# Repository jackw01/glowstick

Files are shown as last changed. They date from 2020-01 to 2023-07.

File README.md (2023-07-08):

# Glowstick

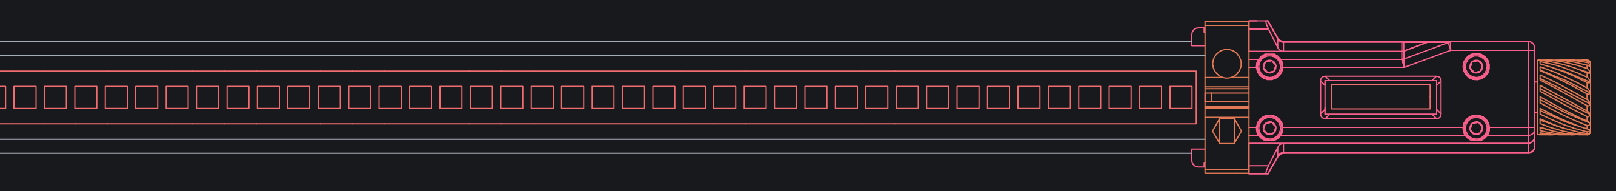
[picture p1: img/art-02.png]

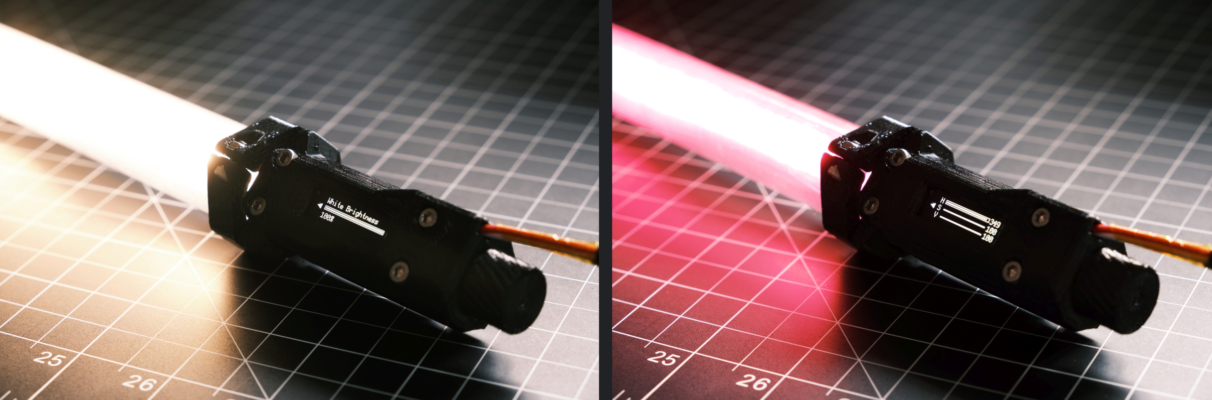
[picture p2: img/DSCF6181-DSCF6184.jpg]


## Features
* Full onboard control with OLED display and rotary encoder
* Uses a SK6812 LED strip for white and RGB light
* Color, white, and gradient modes for full control over lighting
* Animation modes for light painting
* Powered over USB or any other 5V source
* BOM cost less than US$50 for a 24" long light

## Hardware
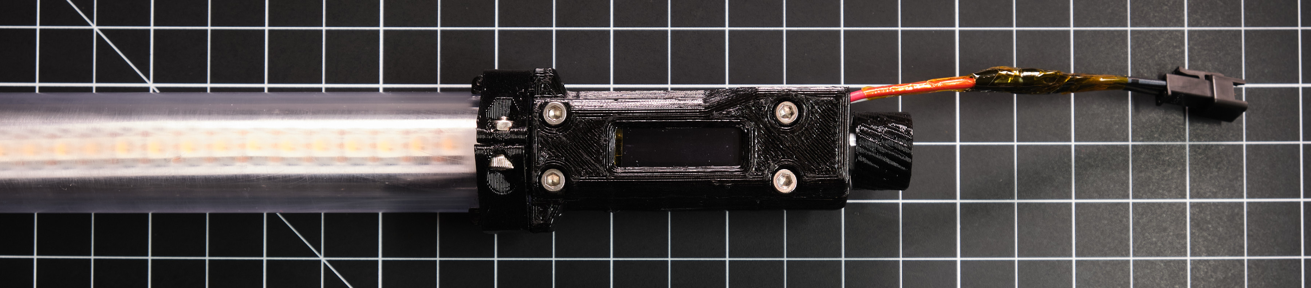
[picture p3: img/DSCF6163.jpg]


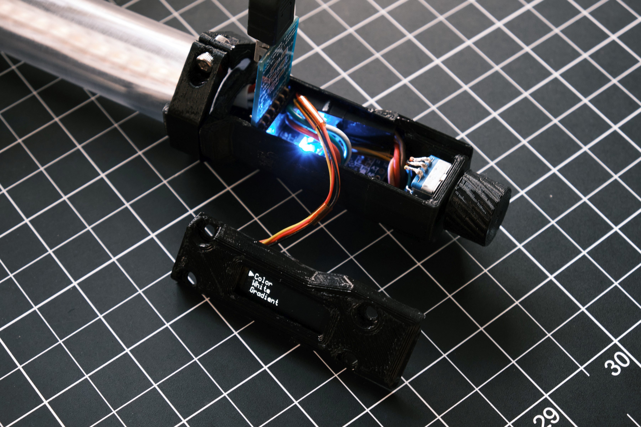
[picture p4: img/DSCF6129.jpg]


### Components used
* Arduino Pro Mini or Pololu A-Star 328PB Micro
* SK6812 RGBW LED strip, 1m length, 144 LED/m IP30
* SSD1306 I2C OLED display breakout board, 128x32 pixels
* EC11 series rotary encoder, push button switch, 15mm knurled shaft (EC11M)
* Clear polycarbonate tube, 1" OD 0.75" ID, 24" length
* Diffusion gel, 24"x1.5" (optional)
* M3 hex socket head cap screws, 4x 20mm and 2x 8mm; 6x M3 hex nuts

## Software

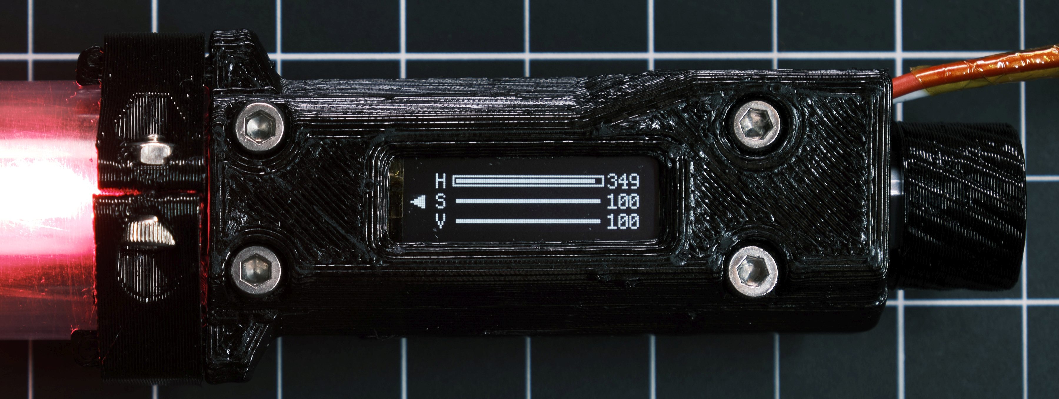
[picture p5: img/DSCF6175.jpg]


[U8g2](https://github.com/olikraus/u8g2) is used for controlling the display and [FastLED](https://github.com/FastLED/FastLED) is used for controlling the LED strips, with some hacks to make it work with RGBW LEDs.

The firmware is built using [PlatformIO](http://docs.platformio.org/en/latest/ide.html#platformio-ide).

## Build your own

### Wiring
All Arduino pin assignments are set in constants.hpp. The defaults are shown below:

```c++
const uint8_t PinLEDs = 2;
const uint8_t PinEncoderA = 3; // must be an external interupt pin
const uint8_t PinEncoderB = 4;
const uint8_t PinEncoderButton = 5;
```

The other contacts for the encoder and button are connected to ground. The display I2C pins connect to Arduino pins A4 (SDA) and A5 (SCL). The 5V and ground wires on the LED strip's connector are connected to the Arduino 5V and ground lines.

### 3D printed parts
STL files for all 3D printed parts can be found in the 3d-printing folder. The original Solidworks design files can be downloaded [here](https://1drv.ms/f/s!AsRZF_y9JrDUn5YvIyRrr59VbNJ60w?e=BrQjPf). All parts should be printed at 100% infill. Supports are required for 20-stick-p001 electronics enclosure, 20-stick-p003 electronics enclosure cover, and 20-stick-p005 encoder knob. I printed everything in PETG; any material should work but stronger ones are recommended. Disable x/y size compensation when printing 20-stick-p005 encoder knob.

There is intentionally no spot in the 3D printed housing for mounting a power connector, as the LED strips used may or may not come with a pre-attached barrel jack and some may prefer a completely different connector type instead. Even with 84 LEDs, current draw is low enough that everything can be powered by a standard USB power bank capable of supplying 2-2.4A at 5V.

The Arduino Pro Mini and the OLED Display are mounted using 3M VHB tape cut to fit the mounting surfaces on their respective parts. The electronics enclosure is designed to accomodate a Pro Mini with a vertical programming header. If yours has a right-angle header, it can be bent up and trimmed by about 2mm to match the dimensions of a vertical header.

### LED strip mounting
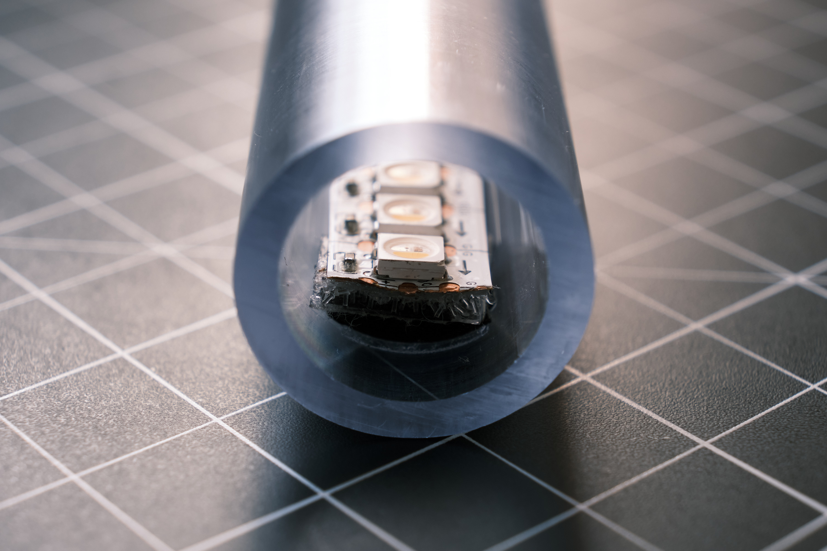
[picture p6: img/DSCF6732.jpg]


I used VHB tape to semi-permanently attach several 3D printed mounting points inside the tube at regular intervals. The LED strip is attached to these mounting points using 3M Dual Lock allowing it to be easily removed and reinstalled later on. A ~1.5"/40mm wide strip of diffusion gel of your choice can be rolled up and inserted into the tube to diffuse the light as desired.

## License
MIT

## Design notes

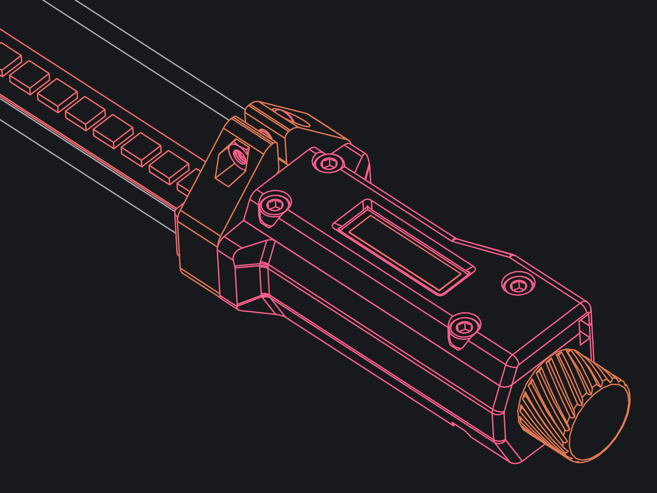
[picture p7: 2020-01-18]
img/art-01.png

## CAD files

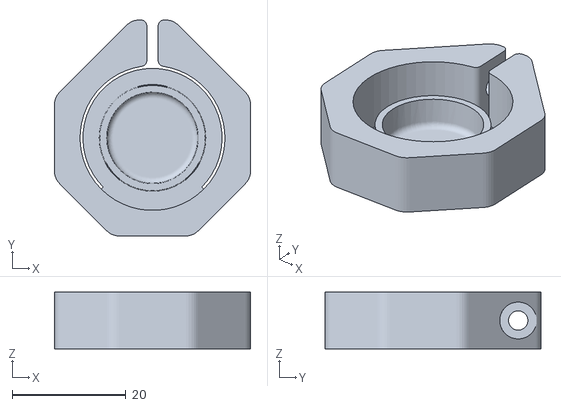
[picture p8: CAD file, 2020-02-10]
3d-printing/20-stick-p007 clamping tube cap.STL
34.5 x 38.0 x 10.0

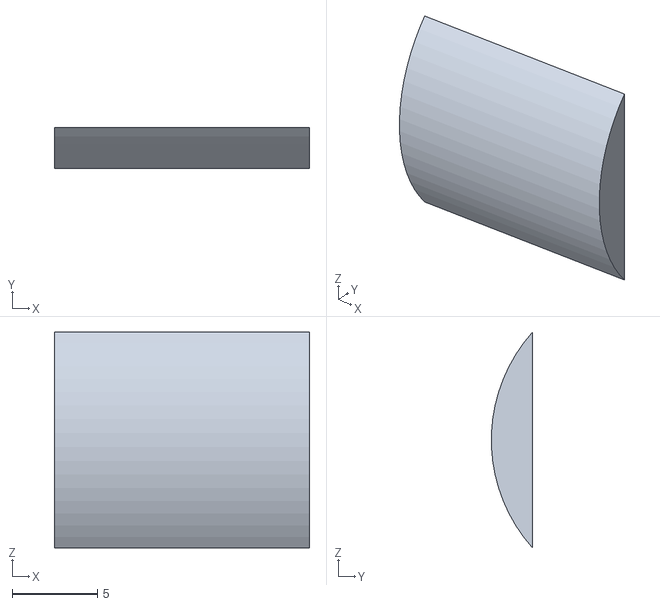
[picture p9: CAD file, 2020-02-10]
3d-printing/20-stick-p010 LED tape spacer.STL
15.0 x 2.42 x 12.7

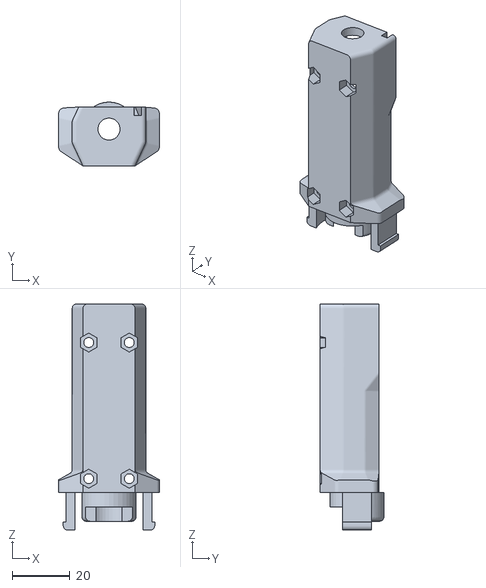
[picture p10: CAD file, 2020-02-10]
3d-printing/20-stick-p001 electronics enclosure.STL
34.8 x 22.0 x 78.0

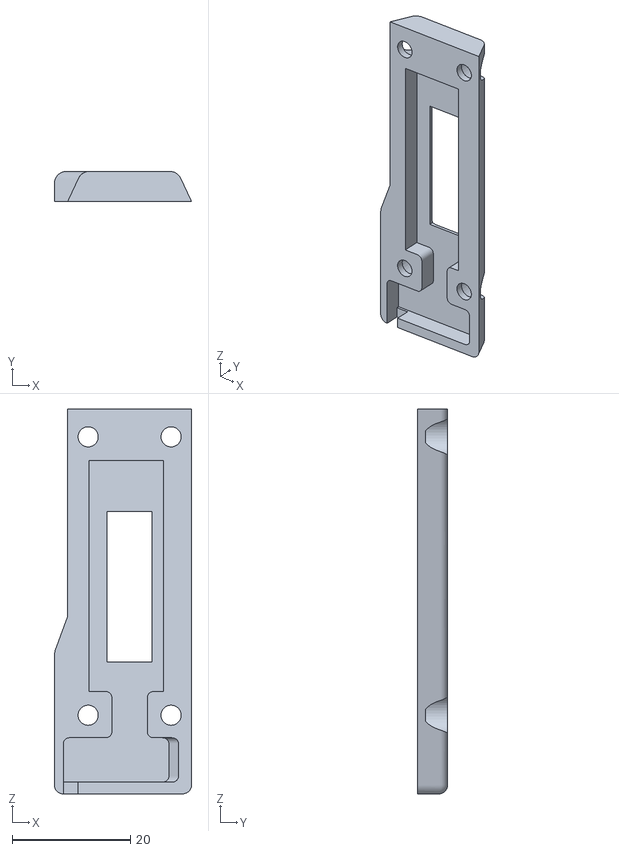
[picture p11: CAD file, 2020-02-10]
3d-printing/20-stick-p003 electronics enclosure cover.STL
23.2 x 5.08 x 65.0

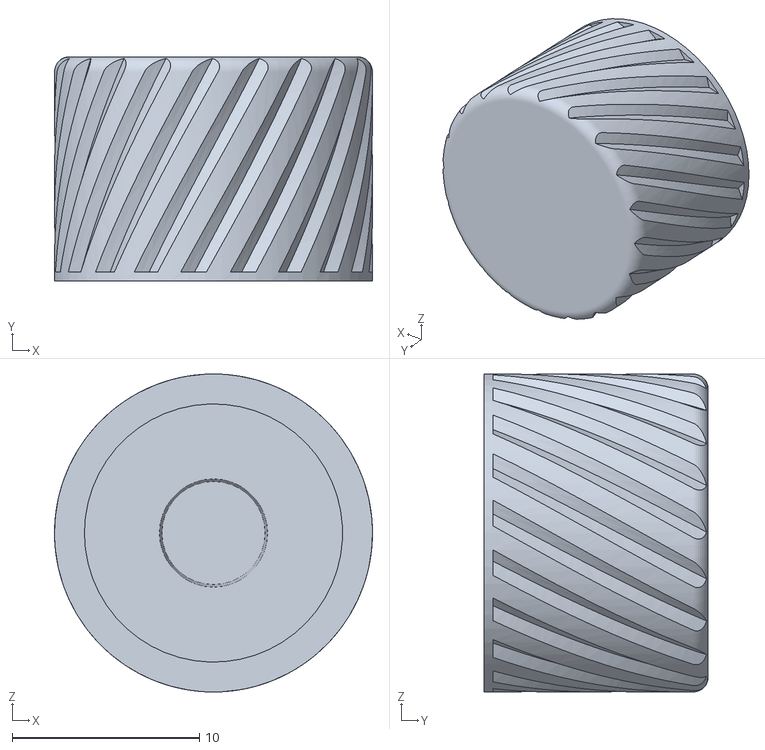
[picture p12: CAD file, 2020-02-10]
3d-printing/20-stick-p005 encoder knob.STL
17.0 x 12.0 x 17.0

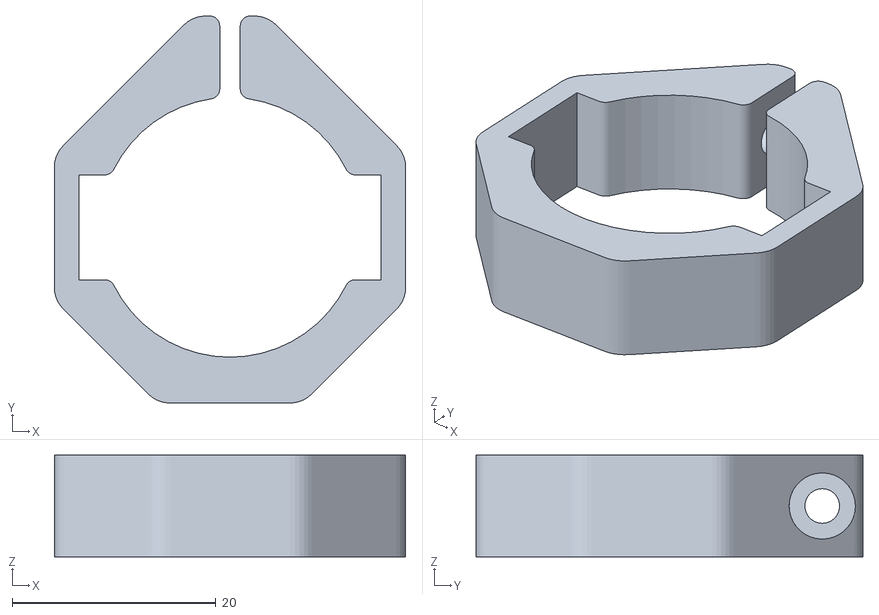
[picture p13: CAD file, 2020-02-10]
3d-printing/20-stick-p008 clamping tube ring.STL
34.5 x 38.0 x 10.0

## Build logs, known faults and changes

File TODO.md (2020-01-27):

### Core Features
- [x] main menu on OLED
- [x] encoder debouncing
- [x] hsv value input screen
- [x] forward/back navigation
- [x] numbers on value inputs
- [x] white brightness input screen
- [x] hue gradient input screen
- [x] display brightness control
- [x] hsv2rgbw
- [x] gradient display
- [x] gradient wrapping
- [x] display timeout
- [x] fade in/out
- [x] startup screen
- [x] animation menu
- [x] variable encoder sensitivity
- [x] animation - cycle hue
- [x] animation - checkerboard
- [x] animation - flash
- [x] animation - diagonal scan
- [x] save white/color pref for animations
- [x] save settings eeprom
- [x] animation scaling
- [x] animation - fire
- [x] use gradient colors for animations
- [x] make encoder controls wrap

### Extras
- [ ] image loading from sd card
- [ ] external input control
- [ ] sound reactive mode

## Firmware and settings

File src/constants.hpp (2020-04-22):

// glowstick
// Copyright 2020 jackw01. Released under the MIT License (see LICENSE for details).

#pragma once

#include "fastledrgbw.hpp"

// Pin mapping
const uint8_t PinLEDs = 2;
const uint8_t PinEncoderA = 3; // must be an external interupt pin
const uint8_t PinEncoderB = 4;
const uint8_t PinEncoderButton = 5;

// LEDs
const uint8_t LEDCount = 84;
const uint8_t LEDSectorCount = 7; // LEDCount % LEDSectorCount = 0, used for some animations
const uint8_t LEDMasterBrightness = 255;
const uint8_t LEDBrightnessRampSpeed = 10; // units/frame
const RGBW LEDOff = RGBW(0, 0, 0, 0);
const CRGB ColorCorrection = CRGB(255, 176, 240);

// Display
const uint8_t CharacterHeight = 8;
const uint8_t LineHeight = 11;
const uint8_t DisplayLines = 3;
const uint16_t DisplayTimeout = 20000; // ms

// Encoder / button
const uint8_t DebounceInterval = 20; // 24 ppr * 20ms = 480ms per rotation min
const uint8_t EncoderCoarseSpeedThreshold = 80; // below this time between pulses, increase speed
const uint8_t EncoderFineAdjustScale = 1; // minimum adjustment speed
const uint8_t EncoderCoarseAdjustScale = 12; // maximum adjustment speed
const float EncoderScaleFloat = 0.025; // fine scale for floating-point number inputs

// Misc
const uint8_t UpdateInterval = 10; // ms per frame

// EEPROM Settings
const uint8_t EEPROMAddrInitialization = 0;
const uint8_t EEPROMAddrDisplayBrightness = 1;
const uint8_t EEPROMAddrHSVValue = 2;
const uint8_t EEPROMAddrWhiteValue = 5; // 3 bytes for hsv
const uint8_t EEPROMAddrGradient0 = 6;
const uint8_t EEPROMAddrGradient1 = 9;

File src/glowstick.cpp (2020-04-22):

// glowstick
// Copyright 2020 jackw01. Released under the MIT License (see LICENSE for details).

#include "glowstick.hpp"

// Encoder interrupt stuff
static int8_t encoderDelta = 0;
static int8_t encoderScale = EncoderFineAdjustScale;
static uint32_t lastEncoderRead = 0;

static void encoderISR() {
  bool b = !digitalRead(PinEncoderB); // Determine whether signal B is high to find direction
  uint32_t time = millis();
  uint32_t dt = time - lastEncoderRead;
  if (dt > DebounceInterval) { // Debounce
    if (b) encoderDelta ++;
    else encoderDelta --;

    // Determine new scale factor
    if (dt < EncoderCoarseSpeedThreshold) encoderScale += 1;
    else encoderScale -= ceil((dt - EncoderCoarseSpeedThreshold) / EncoderCoarseSpeedThreshold);
    encoderScale = constrain(encoderScale, EncoderFineAdjustScale, EncoderCoarseAdjustScale);

    lastEncoderRead = time;
  }
}

// Map a value to a range
static float mapFloat(float in, float inMin, float inMax, float outMin, float outMax) {
  return (in - inMin) * (outMax - outMin) / (inMax - inMin) + outMin;
}

// Wrap a value around a range
static float wrap(float in, float min, float max) {
  if (in >= min && in <= max) return in;
  else if (in < min) return max - (min - in);
  else return min + (in - max);
}

Glowstick::Glowstick() {
}

// Initializes everything
void Glowstick::init() {
  pinMode(PinLEDs, OUTPUT);
  pinMode(PinEncoderA, INPUT_PULLUP);
  pinMode(PinEncoderB, INPUT_PULLUP);
  pinMode(PinEncoderButton, INPUT_PULLUP);

  // Init/read EEPROM
  uint8_t initialized = 0;
  EEPROM.get(EEPROMAddrInitialization, initialized);
  if (initialized != 255) {
    writeEEPROMSettings();
    EEPROM.write(EEPROMAddrInitialization, 255);
  } else {
    EEPROM.get(EEPROMAddrHSVValue, hsvValue);
    EEPROM.get(EEPROMAddrWhiteValue, whiteValue);
    EEPROM.get(EEPROMAddrDisplayBrightness, displayBrightness);
    EEPROM.get(EEPROMAddrGradient0, gradientColors[0]);
    EEPROM.get(EEPROMAddrGradient1, gradientColors[1]);
  }

  cli(); // Disable interrupts before attaching and then enable
  // Having the interrupt on RISING/FALLING breaks everything for some reason (cheap encoders?)
  attachInterrupt(digitalPinToInterrupt(PinEncoderA), encoderISR, LOW);
  sei();

  //Serial.begin(115200);

  CRGB *ledsRGB = (CRGB *) &leds[0]; // Hack to get RGBW to work
  FastLED.addLeds<WS2812B, PinLEDs>(ledsRGB, getRGBWSize(LEDCount));
  FastLED.setBrightness(LEDMasterBrightness);
  setAllLEDs(LEDOff);
  FastLED.show();

  u8g2.begin();
  u8g2.setFontMode(1);

  // Hack to increase brightness range
  u8x8_cad_StartTransfer(u8g2.getU8x8());
  u8x8_cad_SendCmd(u8g2.getU8x8(), 0x0db);
  u8x8_cad_SendArg(u8g2.getU8x8(), 0 << 4); // Replace 0 with Vcom deselect value 0 to 7
  u8x8_cad_EndTransfer(u8g2.getU8x8());
  setScaledDisplayBrightness();

  // Display startup screen
  u8g2.setFont(u8g2_font_logisoso16_tr);
  u8g2.drawStr(0, 16, "GlowStick");
  u8g2.setFont(u8g2_font_profont12_tr);
  u8g2.drawStr(0, 30, "FW v1.0 by jackw01 <3");
  u8g2.sendBuffer();

  delay(800);
}

// Update function, called in a loop
void Glowstick::tick() {
  // Rate limit the loop
  uint32_t time = millis();
  if (time - lastUpdate >= UpdateInterval) {
    //Serial.println(time - lastUpdate);
    // Read encoder and button
    if (encoderDelta != 0) {
      handleEncoderChange();
      encoderDelta = 0;
    }

    bool buttonState = !digitalRead(PinEncoderButton);
    if (buttonState != prevButtonState) {
      if (time - lastButtonChange > DebounceInterval && buttonState) handleButtonPress();
      lastButtonChange = time;
    }
    prevButtonState = buttonState;

    // Update LEDs
    if (displayState == DisplayStateHSV) {
      setAllLEDs(hsv2rgbw(hsvValue, ColorCorrection));
    } else if (displayState == DisplayStateWhite) {
      setAllLEDs(RGBW(0, 0, 0, whiteValue));
    } else if (displayState == DisplayStateGradient) {
      drawGradient(0, LEDCount, gradientColors[0], gradientColors[1]);
    } else if (displayState == DisplayStateAnimation) {
      drawAnimationFrame(time);
    }

    // Ramp brightness up/down
    if (displayState == DisplayStateMenu ||
        displayState == DisplayStateAnimationMenu ||
        displayState == DisplayStateBrightness) {
      ledTransitionState = max(ledTransitionState - LEDBrightnessRampSpeed, 0);
    } else {
      ledTransitionState = min(ledTransitionState + LEDBrightnessRampSpeed, 255);
    }
    FastLED.setBrightness(LEDMasterBrightness * ledTransitionState / 255);
    FastLED.show();

    // Redraw display
    if (displayNeedsRedrawing) {
      u8g2.clearBuffer();
      if (displayState == DisplayStateMenu) drawScrollingMenu(MainMenuStrings);
      else if (displayState == DisplayStateHSV) drawHSVControls();
      else if (displayState == DisplayStateWhite) drawWhiteControls();
      else if (displayState == DisplayStateGradient) drawGradientControls();
      else if (displayState == DisplayStateAnimationMenu) drawScrollingMenu(AnimationMenuStrings);
      else if (displayState == DisplayStateBrightness) drawBrightnessControls();
      else if (displayState == DisplayStateAnimation) drawAnimationControls();
      u8g2.sendBuffer();
      displayNeedsRedrawing = false;
      lastDisplayUpdate = time;
    } else if (time - lastDisplayUpdate > DisplayTimeout) {
      u8g2.clear();
    }

    lastUpdate = time;
  }
}

// Drawing utils

void Glowstick::drawScrollingMenu(const char * const *strings) {
  uint8_t lastItem = scrollOffset + DisplayLines - 1;
  if (currentMenuItem >= lastItem) scrollOffset += currentMenuItem - lastItem;
  if (currentMenuItem < scrollOffset) scrollOffset = currentMenuItem;

  char buffer[MenuStringBufferSize];
  for (uint8_t i = 0; i < currentMenuLength - scrollOffset; i++) {
    if (i + scrollOffset == currentMenuItem) {
      u8g2.drawTriangle(0, i * LineHeight,
                        8, i * LineHeight + CharacterHeight / 2,
                        0, i * LineHeight + CharacterHeight);
    }
    strcpy_P(buffer, (char *)pgm_read_word(&(strings[i + scrollOffset])));
    u8g2.drawStr(10, CharacterHeight + i * LineHeight, buffer);
  }
}

void Glowstick::drawBackButton(bool highlight) {
  if (highlight) u8g2.drawBox(0, 0, 12, u8g2.getDisplayHeight());
  u8g2.setDrawColor(2);
  u8g2.drawTriangle(10, LineHeight,
                    2, LineHeight + CharacterHeight / 2,
                    10, LineHeight + CharacterHeight);
  u8g2.setDrawColor(1);
}

void Glowstick::drawSlider(uint8_t line, uint8_t left, uint8_t width,
                           uint8_t value, uint8_t min, uint8_t max,
                           bool selected, bool active) {
  if (selected) u8g2.drawFrame(left, 1 + line * LineHeight, width, CharacterHeight - 2);
  uint8_t barLength = map(value, min, max, 0, width - 4);
  if (active) {
    u8g2.drawBox(left + 2 + barLength - 1, 3 + line * LineHeight, 3, CharacterHeight - 6);
  } else {
    u8g2.drawBox(left + 2, 3 + line * LineHeight, barLength, CharacterHeight - 6);
  }
}
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

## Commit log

2020-01-07 add encoder stuff
2020-01-08 basic menu display, need to test encoder
2020-01-08 encoder and button with debouncing
2020-01-09 fix some navigation issues and hsv screen appearance
    [constants.hpp, glowstick.cpp, glowstick.hpp]
2020-01-14 led display testing
2020-01-15 fix weird encoder issues, add variable sensitivity
    [constants.hpp, glowstick.cpp, glowstick.hpp]
2020-01-16 hsv2rgbw, but turning encoder causes leds to flash
2020-01-16 gradient drawing, fix fastled hsv issue
    [constants.hpp, glowstick.cpp, glowstick.hpp]
2020-01-18 fix brightness saving, make sure gradients wrap properly
    [constants.hpp, glowstick.cpp, glowstick.hpp]
2020-01-18 animation scale adjustment (needs fixing)
    [glowstick.cpp, glowstick.hpp]
2020-01-27 add fire animation, make encoder controls wrap
2020-02-10 add 3d printed part files
    [20-stick-p001 electronics enclosure.STL, 20-stick-p003 electronics enclosure cover.STL, 20-stick-p005 encoder knob.STL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]
